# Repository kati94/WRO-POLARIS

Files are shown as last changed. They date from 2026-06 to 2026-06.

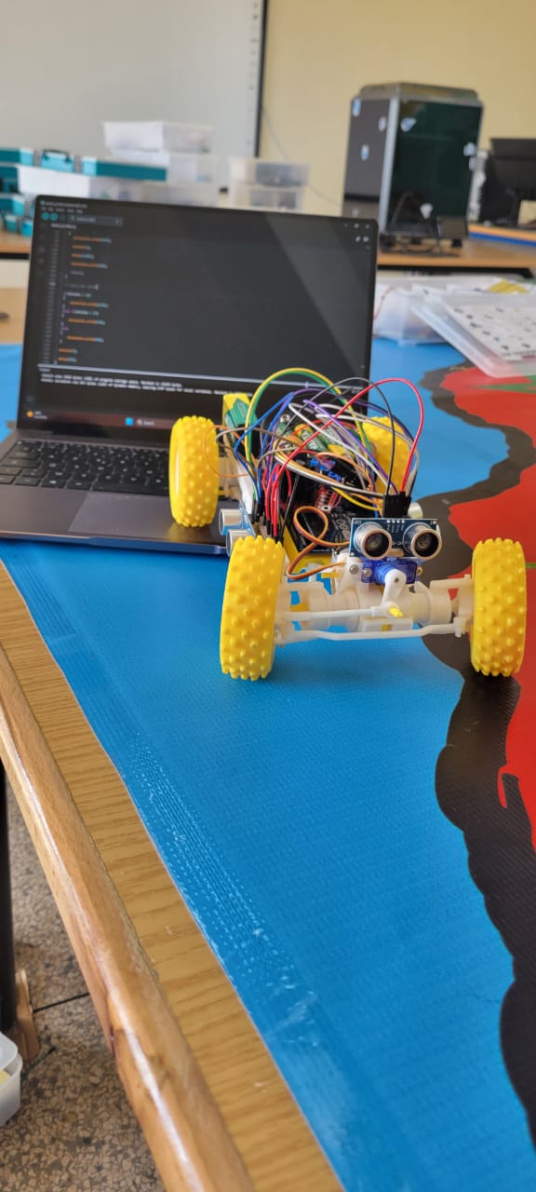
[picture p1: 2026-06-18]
photos/Robot front.jpeg

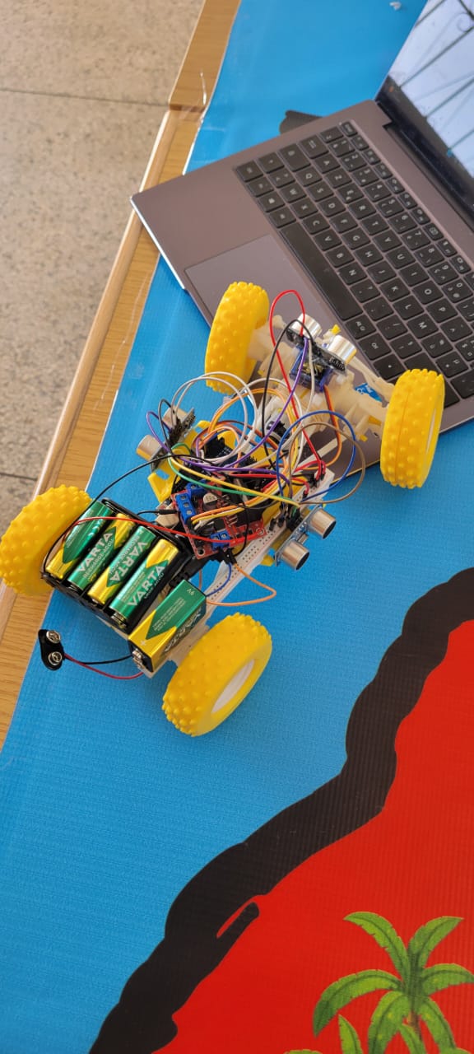
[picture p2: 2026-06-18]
photos/Front.jpeg

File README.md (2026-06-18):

# WRO FUTURE ENGINEERS 2026 - TEAM POLARIS

> An autonomous vehicle developed for the World Robot Olympiad (WRO) Future Engineers category, designed to navigate autonomously, complete three laps, avoid obstacles, and return to the starting area using sensor-based decision making and computer vision.

---

# Team Polaris

## Team Members

Walid Bouzarouata

  Lead Programmer

* Arduino Programming
* Sensor Integration
* Navigation Algorithms
* Testing and Calibration

Adam Saibi

  Mechanical & Electronics Engineer**

* 3D Design and Printing
* Chassis Assembly
* Wiring and Power Management
* Hardware Optimization

---

# Overview

Team Polaris developed a fully autonomous vehicle capable of navigating a WRO Future Engineers track without human intervention.

The robot uses an Arduino Uno as the main controller and combines multiple sensors to perceive its environment and make real-time decisions.

The vehicle is able to:

* Follow track boundaries
* Detect corners
* Count laps
* Detect obstacles
* Perform autonomous navigation
* Return to the starting area

The entire chassis was designed and manufactured using 3D printing technology.

---

# Repository Structure

## photos

Contains photographs of the robot from different angles:

* Front
* Rear
* Left
* Right
* Top
* Bottom

## video

Contains links to demonstration videos.

## schemes

Contains:

* Wiring diagrams
* Electrical schematics
* System architecture

## src

Contains all Arduino source code.

### Main Modules

* Motor Control
* Steering Control
* Ultrasonic Navigation
* MPU6050 Integration
* ESP32-CAM Vision System

## models

Contains STL files for all custom 3D printed parts.

## documentation

Contains engineering notes, testing results, and design explanations.

---

# Project Description

## Challenge

Develop a self-driving vehicle capable of completing the WRO Future Engineers challenges autonomously.

The robot must:

* Complete 3 laps
* Detect corners
* Avoid obstacles
* Adapt to clockwise and counter-clockwise directions
* Return to the starting area

---

# Hardware Used

## Arduino Uno

The Arduino Uno serves as the central controller responsible for:

* Sensor acquisition
* Motor control
* Steering management
* Navigation decisions

---

## HC-SR04 Ultrasonic Sensors

Three ultrasonic sensors are used for:

* Front obstacle detection
* Left wall detection
* Right wall detection

These sensors provide real-time distance measurements that allow the vehicle to navigate safely.

---

## MPU6050 Gyroscope and Accelerometer

The MPU6050 provides orientation data and helps:

* Maintain heading
* Improve turn accuracy
* Measure angular rotation

---

## ESP32-CAM

The ESP32-CAM is used for computer vision tasks including:

* Red obstacle detection
* Green obstacle detection
* Image processing
* Autonomous decision support

---

## MG90S Steering Servo

The steering system uses an MG90S servo motor.

Current steering calibration:

* Right Maximum = 0°
* Center = 80°
* Left Maximum = 150°

---

## DC Motors

The vehicle uses two DC gear motors:

* Front axle drive
* Rear axle drive

The motors provide sufficient torque for autonomous navigation and obstacle avoidance.

---

## Power System

The robot is powered using:

* Rechargeable AA battery pack
* External power bank for logic components

This configuration ensures stable power delivery for motors, sensors, and control electronics.

---

# Software

## Arduino IDE

The vehicle software is developed using Arduino IDE.

---

## Libraries Used

### Servo Library

Used for steering control.

### Wire Library

Used for I²C communication.

### MPU6050 Library

Used for orientation sensing.

### ESP32 Camera Library

Used for image acquisition and processing.

---

# Navigation Strategy

## Open Challenge

The robot:

1. Starts autonomously.
2. Detects the driving direction.
3. Follows track boundaries.
4. Detects corners.
5. Counts laps.
6. Completes three laps.
7. Returns to the starting area.

---

## Obstacle Challenge

The robot:

1. Detects red and green obstacles.
2. Determines the correct passing side.
3. Adjusts its trajectory.
4. Continues lap counting.
5. Completes the challenge autonomously.

---

# 3D Printed Components

Several custom components were designed and manufactured using 3D printing:

* Main chassis
* Sensor mounts
* Camera support
* Battery holder
* Electronic supports
* Steering assemblies

This approach reduced weight and allowed rapid prototyping and testing.

---

# Future Improvements

Planned improvements include:

* Enhanced vision processing
* Improved obstacle classification
* Sensor fusion algorithms
* More precise autonomous parking
* Faster lap completion times

---

# Videos

## Mobility Test

Demonstration of vehicle movement and steering.

## Open Challenge

Three autonomous laps on the official track.

## Obstacle Challenge

Obstacle detection and avoidance demonstration.

---

# Acknowledgments

We would like to thank:

* Our teachers and mentors
* Our school administration
* The WRO organization
* Our families for their support

---

# Team Polaris

**World Robot Olympiad – Future Engineers**

Morocco 🇲🇦

"Learning, Building, Innovating."

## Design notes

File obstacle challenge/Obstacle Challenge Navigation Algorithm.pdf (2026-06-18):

# Obstacle Challenge Navigation Algorithm

## Overview

The Obstacle Challenge extends the Open Challenge by introducing colored obstacles that must be avoided while maintaining autonomous navigation.

The robot combines:

Three HC-SR04 ultrasonic sensors MPU6050 gyroscope
ESP32-CAM vision system
MG90S steering servo
Two DC drive motors
Arduino Uno

The objective is to complete the required laps while correctly passing red and green obstacles.

## Sensor Configuration

Front Ultrasonic Sensor

Used to:

Detect obstacles ahead
Measure safe passing distance Trigger avoidance maneuvers Left Ultrasonic Sensor

Used to:

Monitor distance from left wall Assist during obstacle avoidance Right Ultrasonic Sensor

Used to:

Monitor distance from right wall Assist during obstacle avoidance

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
MPU6050

Used to:

Measure heading changes
Verify turns
Improve maneuver accuracy
ESP32-CAM

Used to:

Detect obstacle colors
Identify red obstacles
Identify green obstacles
Communicate obstacle information to Arduino

## Obstacle Detection Logic

Green Obstacle

When a green obstacle is detected:

Pass on the RIGHT side

The robot adjusts its path to move around the obstacle while maintaining track awareness.

Red Obstacle

When a red obstacle is detected:

Pass on the LEFT side

The robot modifies its trajectory to safely avoid the obstacle.

## Navigation Strategy

Normal Driving

The robot follows the wall using ultrasonic sensors exactly as in the Open Challenge.

•
•
•

•
•
•
•

Follow wall
↓
Detect corner
↓
Turn
↓
Continue

Obstacle Encounter

When the front ultrasonic detects an object within a predefined distance:

Obstacle detected

The robot:

Reduces speed.
Requests obstacle color from ESP32-CAM. Determines avoidance side.
Executes avoidance maneuver.
Returns to normal navigation.

## Green Obstacle Maneuver

Obstacle detected
↓
Color = Green
↓
Move Right
↓
Pass obstacle
↓
Return to center path

## Red Obstacle Maneuver

Obstacle detected
↓

1.
2.
3.
4.
5.

Color = Red
↓
Move Left
↓
Pass obstacle
↓
Return to center path

## Corner Priority

Track navigation has higher priority than obstacle avoidance.

If a corner and obstacle are detected simultaneously:

Complete the corner safely.
Re-evaluate obstacle position.
Execute avoidance maneuver.

## Gyroscope Usage

The MPU6050 is used to:

Maintain heading during obstacle avoidance. Measure steering corrections.
Return accurately to the original trajectory.

## Pseudocode

1.
2.
3.

•
•
•

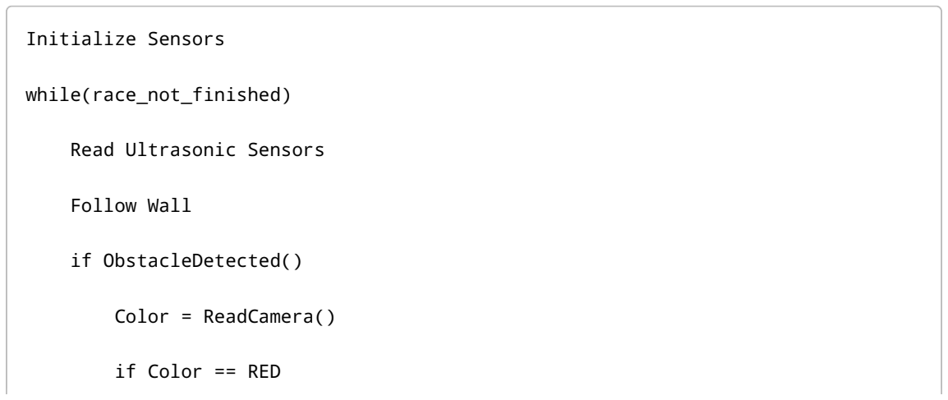
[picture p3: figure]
Initialize Sensors; while(race_not_finished); Read Ultrasonic Sensors; Follow Wall; if ObstacleDetected(); Color = ReadCamera(); if Color == RED

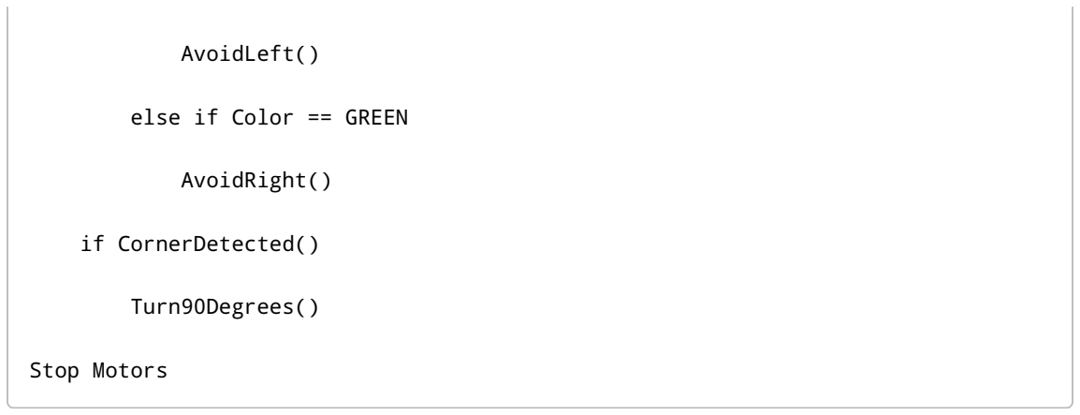
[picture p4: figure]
AvoidLeft(); else if Color == GREEN; AvoidRight(); if CornerDetected(); Turn90Degrees(); Stop Motors

## ESP32-CAM Communication

ESP32-CAM sends simple commands to Arduino:

R = Red Obstacle

G = Green Obstacle

N = No Obstacle

Example:

R

Arduino executes:

AvoidLeft()

Example:

G

Arduino executes:

AvoidRight()

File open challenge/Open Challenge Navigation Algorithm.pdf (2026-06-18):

## Open Challenge Navigation Algorithm

## Overview

The robot is designed to complete three autonomous laps around the WRO Future Engineers track.

The navigation system combines:

- Three HC-SR04 ultrasonic sensors
- MPU6050 gyroscope
- MG90S steering servo
- Two DC drive motors
- Arduino Uno

## Sensor Configuration

Front Ultrasonic Sensor

Used to detect:

- Walls
- Corners
- Obstacles directly ahead
Left Ultrasonic Sensor

Used to measure the distance to the left wall. Right Ultrasonic Sensor

Used to measure the distance to the right wall. MPU6050

Used to:

- Measure heading changes
- Verify 90° turns
- Count completed corners

## Steering Calibration

Position | Servo Value
Maximum Right 0
Straight | 80
Maximum Left | 150

## Main Navigation Strategy

1. Start

The robot initializes all sensors and centers the steering system.
2. Wall Following

The vehicle continuously reads the right ultrasonic sensor.

If the robot gets too close to the wall:

- Steering is adjusted slightly left.

If the robot moves too far from the wall:

- Steering is adjusted slightly right.

If the distance is within the target range:

- The robot continues straight.
3. Corner Detection

A corner is detected when:

- The right wall disappears.
- The front sensor detects an approaching wall.
4. Turning

When a corner is detected:

1. Steering moves to maximum right.
2. The robot continues moving.
3. The MPU6050 measures the heading change.
4. When approximately 90 degrees are reached:
- Steering returns to center.

- Corner counter increases by one.
5. Lap Counting

Each completed corner increments the turn counter.

- 4 turns = 1 lap
- 8 turns = 2 laps
- 12 turns = 3 laps
6. Finish

After completing 12 turns:

- Motors stop.
- Steering returns to center.
- The robot waits for reset.

## Pseudocode

Initialize Sensors

while(turns < 12)

Read Front Sensor
Read Left Sensor
Read Right Sensor

if CornerDetected()

TurnRight90Degrees()

turns++

else

FollowRightWall()

Stop Motors

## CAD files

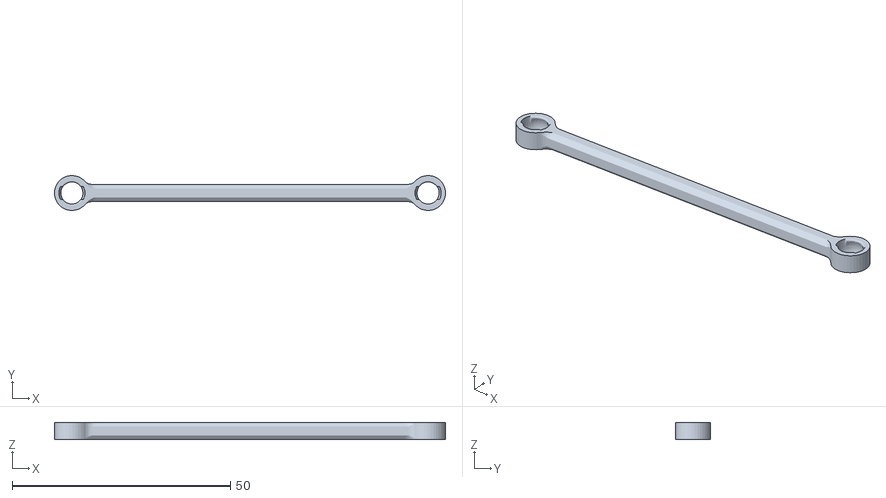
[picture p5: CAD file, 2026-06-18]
models/28.stl
89.6 x 8.00 x 4.00

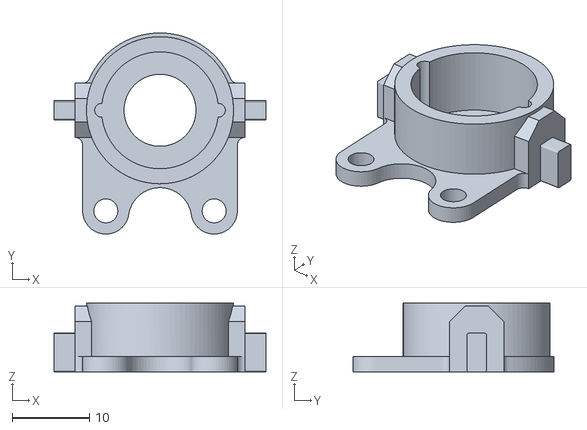
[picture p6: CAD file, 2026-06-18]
models/04.stl
27.4 x 26.0 x 8.90

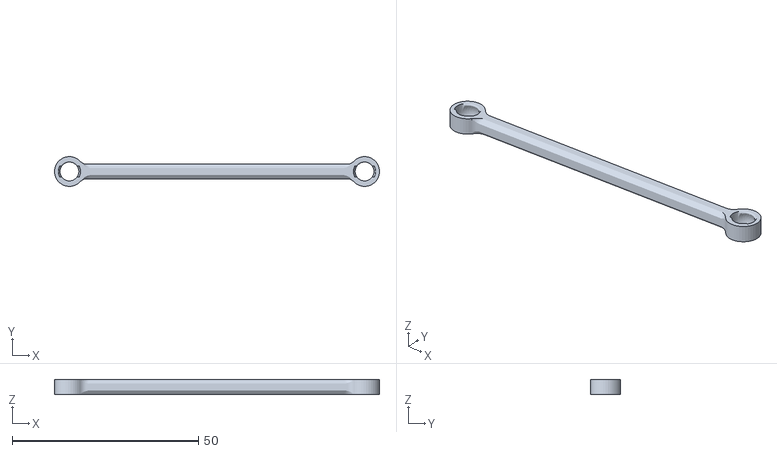
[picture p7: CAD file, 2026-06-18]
models/20.stl
87.2 x 7.98 x 4.00

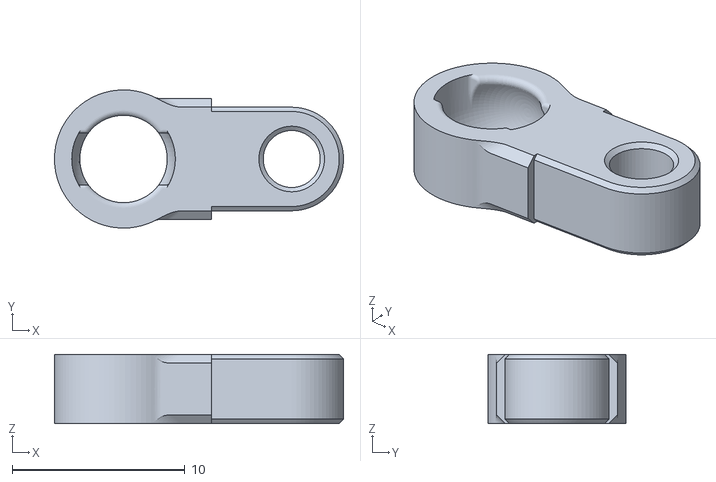
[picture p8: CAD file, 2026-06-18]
models/32.stl
16.7 x 8.00 x 4.00

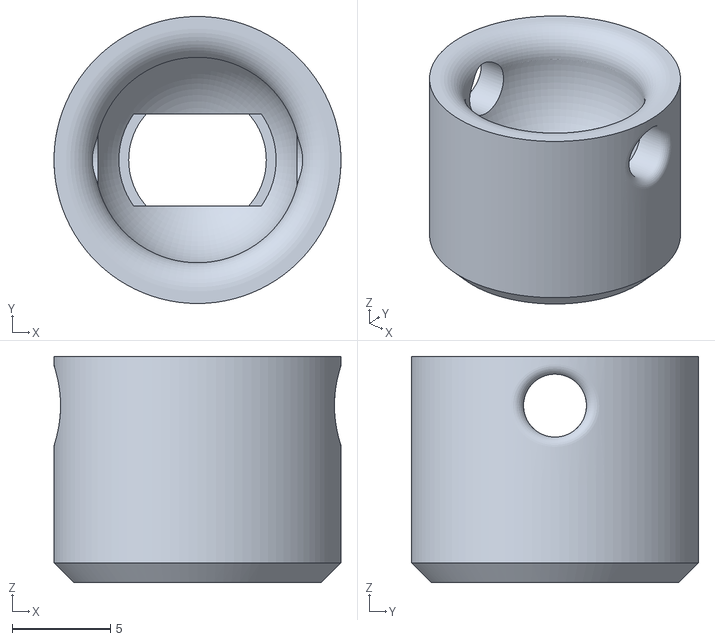
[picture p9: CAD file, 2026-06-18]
models/02.stl
14.6 x 14.6 x 11.5

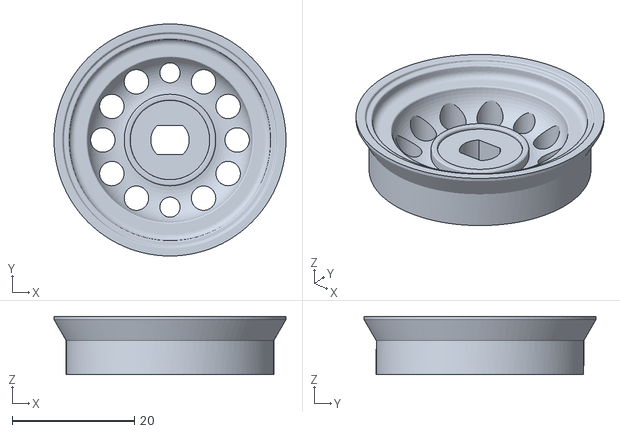
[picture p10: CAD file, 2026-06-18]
models/30.stl
38.0 x 38.0 x 9.50

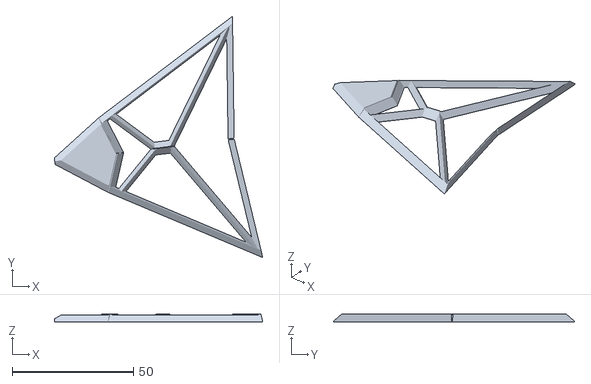
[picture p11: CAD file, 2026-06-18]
models/Ram_2.stl
86.0 x 99.4 x 3.24

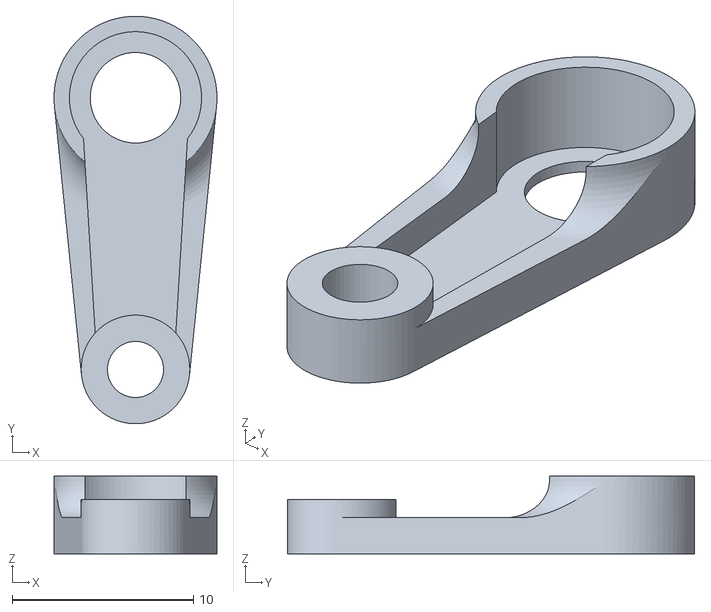
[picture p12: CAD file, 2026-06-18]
models/11.stl
9.00 x 22.5 x 4.30

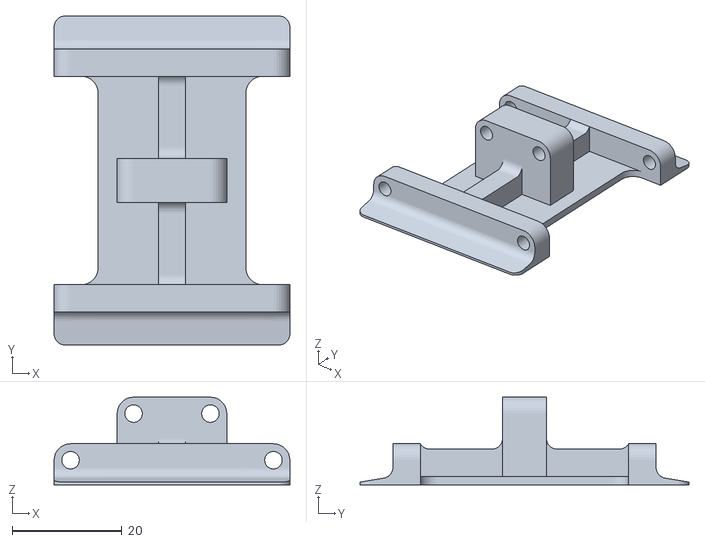
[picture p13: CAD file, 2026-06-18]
models/19.stl
43.0 x 60.0 x 16.0

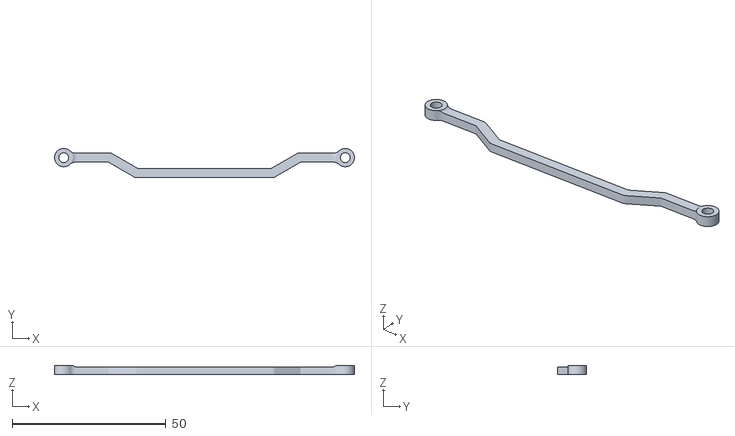
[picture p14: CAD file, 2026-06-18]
models/10.stl
97.6 x 9.50 x 3.00

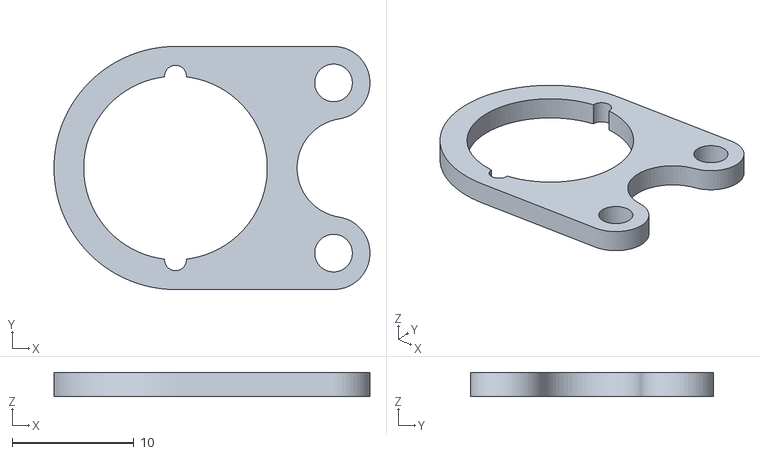
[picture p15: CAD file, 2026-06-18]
models/05.stl
26.0 x 20.0 x 2.00

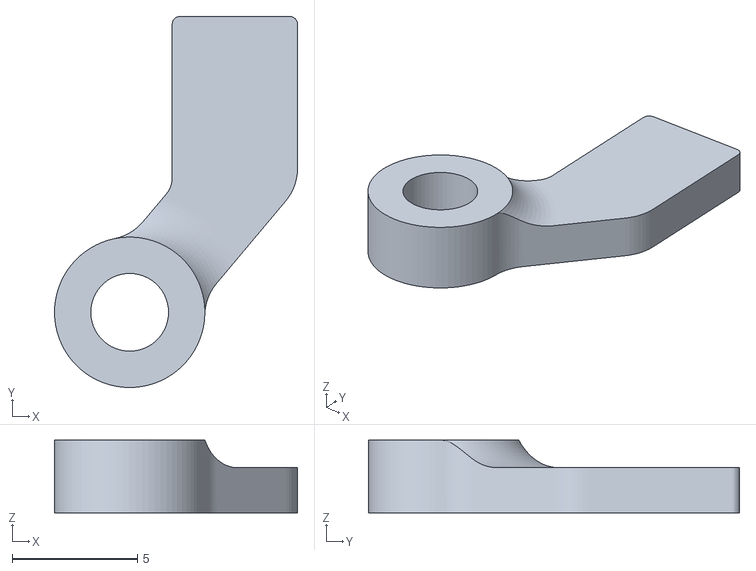
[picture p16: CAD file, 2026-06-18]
models/09.stl
9.70 x 14.8 x 2.90

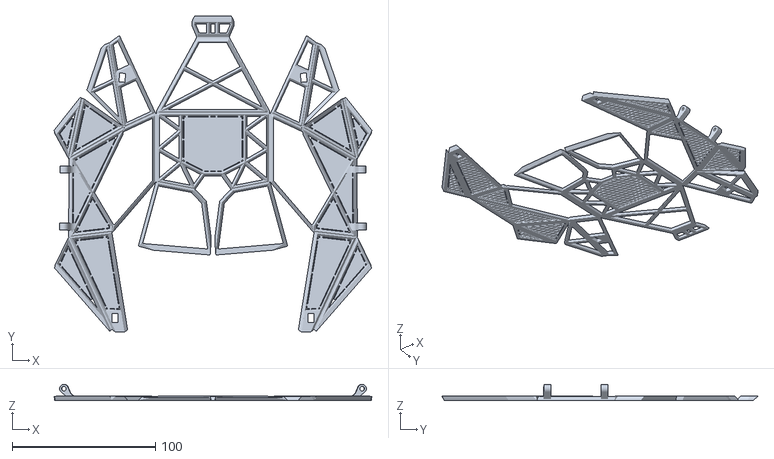
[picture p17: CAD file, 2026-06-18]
models/Ram_1.stl
221.8 x 220.6 x 11.2

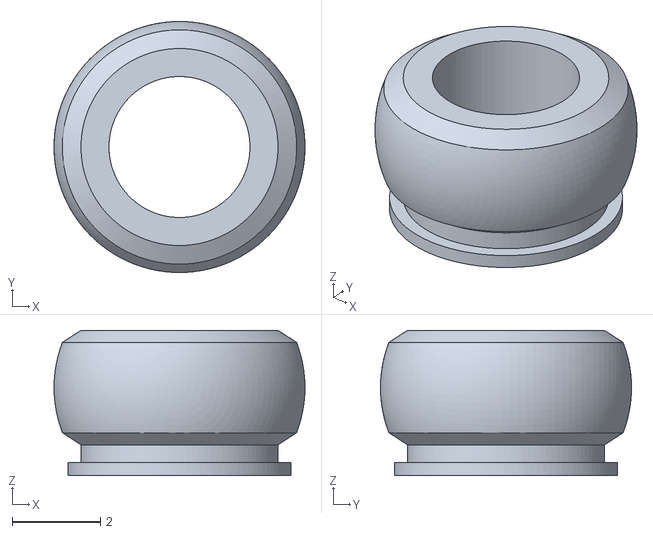
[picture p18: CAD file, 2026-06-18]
models/13.stl
5.70 x 5.70 x 3.30

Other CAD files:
models/07.stl
models/31.stl
models/03.stl
models/Ram_3.stl
models/01.stl
models/06.stl
models/21.stl
models/Pneu.stl

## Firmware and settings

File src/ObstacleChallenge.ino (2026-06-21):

#include <Wire.h>
#include <MPU6050_tockn.h>
#include <Servo.h>
#include <SoftwareSerial.h>

SoftwareSerial camSerial(A0, A1);

MPU6050 mpu(Wire);

#define TRIG_FRONT 6
#define ECHO_FRONT 7

#define TRIG_RIGHT 11
#define ECHO_RIGHT 12

#define TRIG_LEFT 9
#define ECHO_LEFT 10

#define START_BUTTON 13

Servo direction; 

int motorA1 = 2;
int motorA2 = 3;

int motorB1 = 5;
int motorB2 = 4;

int clockwise ;

int cornercount = 0;
char obstacleColor = 'N';

void avancer()
{
  digitalWrite(motorA1, LOW);
  digitalWrite(motorA2, HIGH);

  digitalWrite(motorB1, LOW);
  digitalWrite(motorB2, HIGH);
}

void stopMotors()
{
  digitalWrite(motorA1, LOW);
  digitalWrite(motorA2, LOW);

  digitalWrite(motorB1, LOW);
  digitalWrite(motorB2, LOW);
}
void reculer()
{
  digitalWrite(motorA1, HIGH);
  digitalWrite(motorA2, LOW);

  digitalWrite(motorB1, HIGH);
  digitalWrite(motorB2, LOW);
}
void recoverRight()
{
  Serial.println("RECOVERY MODE");

  stopMotors();
  delay(200);

  // Reverse
  reculer();
  delay(700);

  stopMotors();
  delay(200);

  // Turn right
  turnRight170();

  Serial.println("RECOVERY COMPLETE");
}
void recoverLeft()
{
  Serial.println("RECOVERY MODE");

  stopMotors();
  delay(200);

  // Reverse
  reculer();
  delay(700);

  stopMotors();
  delay(200);

  // Turn right
  turnRight170();

  Serial.println("RECOVERY COMPLETE");
}
float readDistance(int trigPin, int echoPin)
{
  digitalWrite(trigPin, LOW);
  delayMicroseconds(2);

  digitalWrite(trigPin, HIGH);
  delayMicroseconds(10);

  digitalWrite(trigPin, LOW);

  long duration = pulseIn(echoPin, HIGH, 25000);

  // No echo received
  if(duration == 0)
  {
    return 300;
  }

  float distance = duration * 0.0343 / 2.0;

  return distance;
}

void avoidRed()
{
  direction.write(75);  // steer right

  avancer();
  delay(600);

  direction.write(105);  // center

  avancer();
  delay(600);

  direction.write(140); // return left

  avancer();
  delay(600);

  direction.write(105);
}
void avoidGreen()
{
  direction.write(140); // steer left

  avancer();
  delay(600);

  direction.write(105);

  avancer();
  delay(600);

  direction.write(75);  // return right

  avancer();
  delay(600);

  direction.write(105);
}
void turnRight170()
{
  
  mpu.update();

  float startAngle = mpu.getAngleZ();
  Serial.print("start:"); Serial.print(startAngle, 0);

  direction.write(65);   // your calibrated right angle 165  105  65

  avancer();

  while(true)
  {
    mpu.update();

    float currentAngle = mpu.getAngleZ();

    // -170 right 
    if(currentAngle <= startAngle - 110)
    {
      break;
    }
  }
  cornercount ++;

  stopMotors();

  direction.write(105); //centre

  delay(300);
}

void turnLeft170()
{
  
  mpu.update();

  float startAngle = mpu.getAngleZ();
  Serial.print("start:"); Serial.print(startAngle, 0);

  direction.write(165);   // your calibrated right angle

  avancer();

  while(true)
  {
    mpu.update();

    float currentAngle = mpu.getAngleZ();

    if(currentAngle >= startAngle + 110)
    {
      break;
    }
  }

  cornercount ++;

  stopMotors();

  direction.write(105);

  delay(300);
}

void setup() {
  // put your setup code here, to run once:
  pinMode(motorA1, OUTPUT);
  pinMode(motorA2, OUTPUT);
  pinMode(motorB1, OUTPUT);
  pinMode(motorB2, OUTPUT);
  direction.attach(8);
  Serial.begin(115200);
  camSerial.begin(9600);

  pinMode(TRIG_FRONT, OUTPUT);
  pinMode(ECHO_FRONT, INPUT);

  pinMode(TRIG_RIGHT, OUTPUT);
  pinMode(ECHO_RIGHT, INPUT);

  pinMode(TRIG_LEFT, OUTPUT);
  pinMode(ECHO_LEFT, INPUT);

  Wire.begin();
  Serial.println("Calibrating gyro - keep STILL!");
  mpu.begin();
  mpu.calcGyroOffsets(true);
  Serial.println("Ready.");

  for (int i = 3; i > 0; i--) {
    direction.write(105);
    Serial.print(i); Serial.println("...");
    delay(1000);
  }
  Serial.println(">>> GO!");

}

void loop()
{
  if(camSerial.available())
  {
  obstacleColor = camSerial.read();
  }
  Serial.print("Color: ");
  Serial.println(obstacleColor);
  
  // finish after 12 corners (3 laps)
  if (cornercount >= 12) {
    stopMotors();
    direction.write(105);
    Serial.println("DONE - 3 laps");
    while (true) delay(100);
  }

  float front = readDistance(TRIG_FRONT, ECHO_FRONT);
  float left  = readDistance(TRIG_LEFT, ECHO_LEFT);
  float right = readDistance(TRIG_RIGHT, ECHO_RIGHT);

  if(front < 25)
{
   stopMotors();

   if(obstacleColor == 'R')
   {
      Serial.println("GO RIGHT");
      avoidRed();
   }
   else if(obstacleColor == 'G')
   {
      Serial.println("GO LEFT");
      avoidGreen();
   }
  }

  if(front < 10)
  {
    if(clockwise == 1)
  {
   recoverRight();
  }
  else
  {
   recoverLeft();
  }
  }
  // -------- CORNER DETECTION --------
  if(front < 40)
  {
    

    if(left < 18 && right > 25){
      Serial.print("Right turn");
      clockwise = 1;
      turnRight170();
      
    }

    else if (right < 18 && left > 25)
    {
      Serial.print("Left turn");
      clockwise = 0;
      turnLeft170();

    }else{
      return;
    }
  }

  // -------- LANE CENTERING --------
  float error = left - right;

  int steer = 105; // center position

  if(error > 5)       // too close to right wall
  {
    steer = 130;
  }
  else if(error < -5) // too close to left wall
  {
    steer = 75;
  }
  else
  {
    steer = 105;
  }

  direction.write(steer);

  avancer();

  //Serial.print("F=");
  Serial.print(front);

  //Serial.print(" L=");
  Serial.print(left);

 // Serial.print(" R=");
  Serial.print(right);

  //Serial.print(" S=");
  Serial.println(steer);

  delay(30);
}
